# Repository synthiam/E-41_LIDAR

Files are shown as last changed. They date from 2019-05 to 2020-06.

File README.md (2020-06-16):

# E-41 LIDAR

**Project Status:** Prototype

If you are new to GitHub and would like to create a derivative of this project, please have a look at GitHub instructions to [fork a repo](https://help.github.com/en/articles/fork-a-repo)

## Description

Out of our passion to solve the issue of time waste in the robot creation process, ARC was born. The ARC software platform reduces the time it takes to get from idea to implementation. Since 2011 we have been listening to the challenges robot builders encounter and continue to provide them with an ever expanding toolbox of solutions. Join us on this journey!

We didn't stop at the software, we also made time saving hardware solutions. This LIDAR reference design is one of them. This reference design simplifies the communication from the LIDAR and allows it easily interface to ARC. ARC then gives a visual representation of the data and starts mapping the area. We want to share these files with you so you can create your own version for your community and customers to enjoy!

**Features:**
- I2C breakout
- EZ-B Camera breakout
- LIDAR communication breakout
- SWD programming header
- 5V tolerant I/O pins
- Mounting points for LIDAR unit
- 5V energy efficient switching power supply
- ARC skill available
- Reverse polarity protection
- Bicolor Blue/red indicator LED
- Voltage requirement: 5-16VDC (7.4V Typical)
- Dimensions: 149.4(W) x 95.3(L) x 39.6(H) (mm)
- Weight: 166g

**Major components:** 
- STM32F401RBT6 ARM microcontroller (custom firmware provided)
- RT8299GSP Switching power supply 
- HLS-LFCD2 LIDAR unit

**Manufacturing notes:** 
1. Supplier: programs custom firmware into the STM32F401RBT6 at their facility before sending to manufacturer
2. Supplier: provides LIDAR unit
3. Manufacturer: Single side placement and soldering of SMT components
4. Manufacturer: Single Side soldering of THT components
5. Manufacturer: Assembles PCB and LIDAR unit together

## Contents

[**Documentation:**](https://github.com/synthiam/E-41_LIDAR/tree/master/E-41%20Documentation) Schematic PDF, Datasheet PDF, BOM

[**Hardware:**](https://github.com/synthiam/E-41_LIDAR/tree/master/E-41%20Hardware) Altium PCB design File, Altium SCH Design File

*Altium Libraries are also available <a href="https://github.com/synthiam/Synthiam_Altium_Librairies">here</a>*

## Photos

<p align="left">

</p>

## ARC Skill

The ARC Skill for this reference design is very easy to use. Simply add an animation frame, click on the pixels, choose the color, and repeat! Activate the animations with the click of a mouse button or with code. 

Link: https://synthiam.com/Software/Manual/EZ-LIDAR-SLAM-15944



## Contact

For profit use of these files requires written consent. Contact partners@synthiam.com. For everyone else, party on!

Synthiam Website: https://synthiam.com

## License

This project is released under the following licenses:

**Hardware:** Creative Commons Plus Attribution-NonCommercial 4.0 International (CC+ BY-NC 4.0)

**Firmware:** Apache 2.0 + “Commons Clause” License Condition v1.0

Please see [LICENSE.md](https://github.com/synthiam/E-41_LIDAR/blob/master/LICENSE.md) for license details.



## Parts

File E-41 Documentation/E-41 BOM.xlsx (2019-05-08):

Qty | Description | Manufacturer Part No. | Alternative | Designator | Custom Information | Link
E-41 LIDAR
1 | 2 layer, Blue soldermask, White silkscreen, ENIG | LIDAR PCB |  | PCB
1 | 120MHz 32-bit ARM processor | STM32F401RBT6 |  | U1 | Needs Main Firmware programmed onto chip before manufacturing | https://www.digikey.ca/product-detail/en/stmicroelectronics/STM32F401RBT6/497-17428-ND/4755972
1 | Buck Converter 3A 8SOP | RT8299GSP | RT8299ZSP | U2 |  | https://www.digikey.ca/product-detail/en/richtek-usa-inc/RT8299GSP/RT8299GSPCT-ND/5253202
1 | 3.3V Regulator SOT-25 | SPX3819M5-L-3-3/TR |  | VR1 |  | https://www.digikey.ca/product-detail/en/maxlinear-inc/SPX3819M5-L-3-3-TR/1016-1873-1-ND/3586590
1 | 2.1mm Barrel Jack, through-hole mount | PJ-002A | 18741 | PWR JCK |  | http://www.4uconnector.com/online/itemagrid.asp?seriesdesp=DC+JACK+DIP+90%C2%B0+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
1 | 6.8uH 2.3A Inductor SMD | NR5040T6R8M |  | L2 |  | https://www.digikey.ca/product-detail/en/taiyo-yuden/NR5040T6R8M/587-2374-1-ND/2178987
1 | 25MHz crystal, 18pF load, 2-SMD package | 7A-25.000MAAJ-T | ABM3-25.000MHZ-D2Y-T | XTAL |  | http://www.digikey.ca/product-detail/en/7A-25.000MAAJ-T/887-1092-1-ND/2118969
2 | 5A 30V SOD128 Schottky Diode | PMEG3050EP, 115 |  | D1, D2 |  | https://www.digikey.ca/product-detail/en/nexperia-usa-inc/PMEG3050EP115/1727-5317-1-ND/2676793
1 | Ferrite Bead 0603 30ohm @ 100MHz | CIC10P300NC |  | L1
2 | 10Kohm 0603 Resistor 1% | RC0603FR-0710KL |  | R1, R7
1 | 27Kohm 0603 Resistor 1% | RC0603FR-0727KL |  | R3
2 | 680ohm 0603 Resistor | RC0603JR-07680RL |  | R5, R6
1 | 5.1Kohm 0603 Resistor 1% | RC0603FR-075K1L |  | R4
1 | 18Kohm 0603 Resistor 1% | RC0603FR-0718KL |  | R2
2 | 47uF 10V 1206 Ceramic Capacitor | GRM31CR61A476ME15L |  | C10, C11
1 | 100uF 16V Aluminum Electrolytic Capacitor SMD | EEE-FT1C101AR |  | C2
2 | 2.2uF 16V 0603 Ceramic Capacitor | CC0603ZRY5V7BB225 |  | C4, C8
2 | 18pF 50V 0603 Cermic Capacitor | C0603C180J5GACTU |  | C6, C7
5 | 0.1uF 16V 0603 Ceramic Capacitor | C0603C104K4RACTU |  | C1, C3, C5, C9, C13
1 | LED Red/Blue Side View 1210 | IN-S121DAS5R5B |  | LED1 |  | https://www.digikey.ca/product-detail/en/inolux/IN-S121DAS5R5B/1830-1043-1-ND/7604656
1 | 4 position JST-PH connector | B4B-PH-K-S(LF)(SN) | 01530 | P5 |  | https://www.digikey.ca/products/en?keywords=%09455-1706-ND
2 | 6 position JST-PH connector | B6B-PH-K-S(LF)(SN) | 01536 | P6, P7 |  | https://www.digikey.ca/products/en?keywords=B6B-PH-K-S(LF)(SN)
1 | 2 position JST-PA connector | SM02B-PASS-TBT(LF)(SN) |  | P2 |  | https://www.digikey.ca/product-detail/en/jst-sales-america-inc/SM02B-PASS-TBT-LF-SN/455-2650-1-ND/2773439
1 | 6 position JST-GH connector | SM06B-GHS-TB(LF)(SN) |  | P3 |  | https://www.digikey.ca/product-detail/en/jst-sales-america-inc/SM06B-GHS-TB-LF-SN/455-1568-1-ND/807836
2 | 40-pin White Male 0.1" pitch Header |  |  | P8, P9, P10, P11 | This header needs to be broken down into 4 x 16-pin | https://www.adafruit.com/product/4149
1 | 40-pin Black Male 0.1” pitch header | FIT0084-B | 00834 | P1, P4, P12 | This header needs to be broken down into 1 x 4-pin, 1 x 5-pin and 1 x 2-pin | http://www.4uconnector.com/online/SearchPro.asp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

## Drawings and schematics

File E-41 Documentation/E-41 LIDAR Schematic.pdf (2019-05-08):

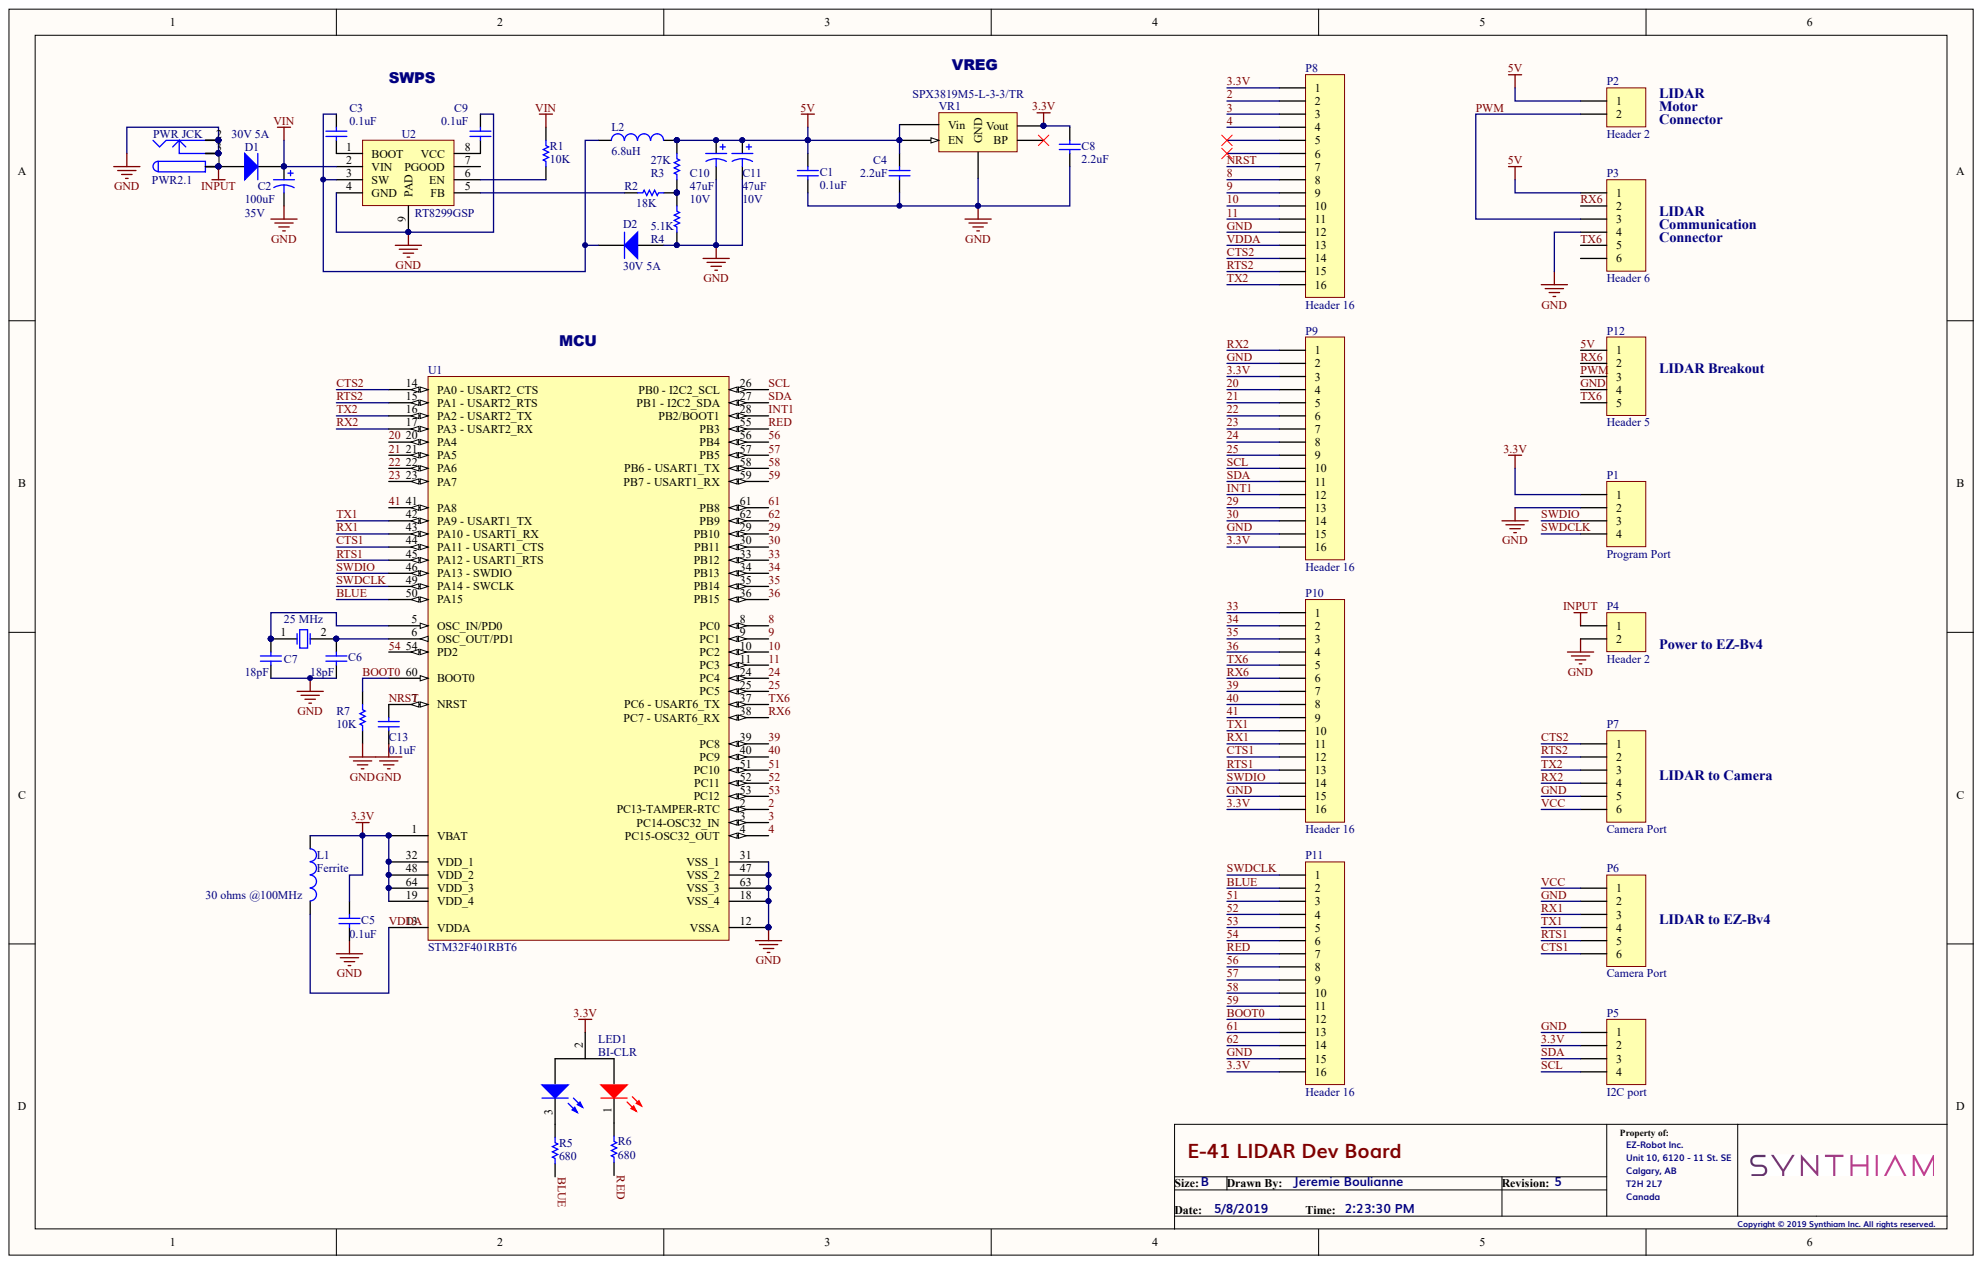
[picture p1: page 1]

E-41 LIDAR Dev Board | Property of: EZ-Robot Inc. Unit 10, 6120 - 11 St. SE Calgary, AB T2H 2L7 Canada

B Size: | Jeremie Boulianne Drawn By: | 5 Revision:
5/8/2019 2:23:30 PM Date: Time:

Copyright © 2019 Synthiam Inc. All rights reserved.
